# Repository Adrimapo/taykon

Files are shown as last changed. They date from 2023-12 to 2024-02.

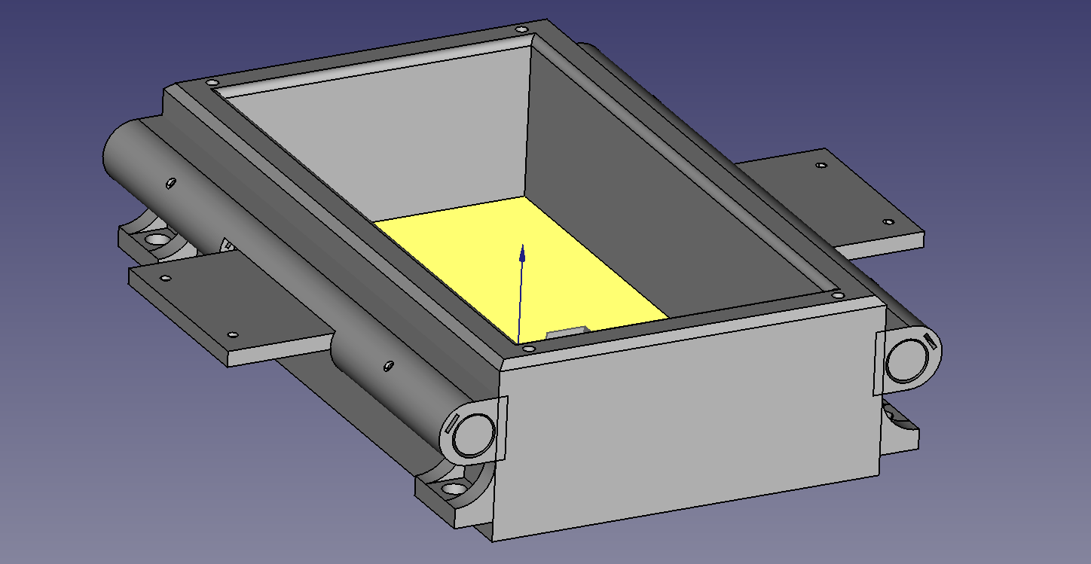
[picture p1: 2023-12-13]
resources/resources_shell/concepto-inicial.png

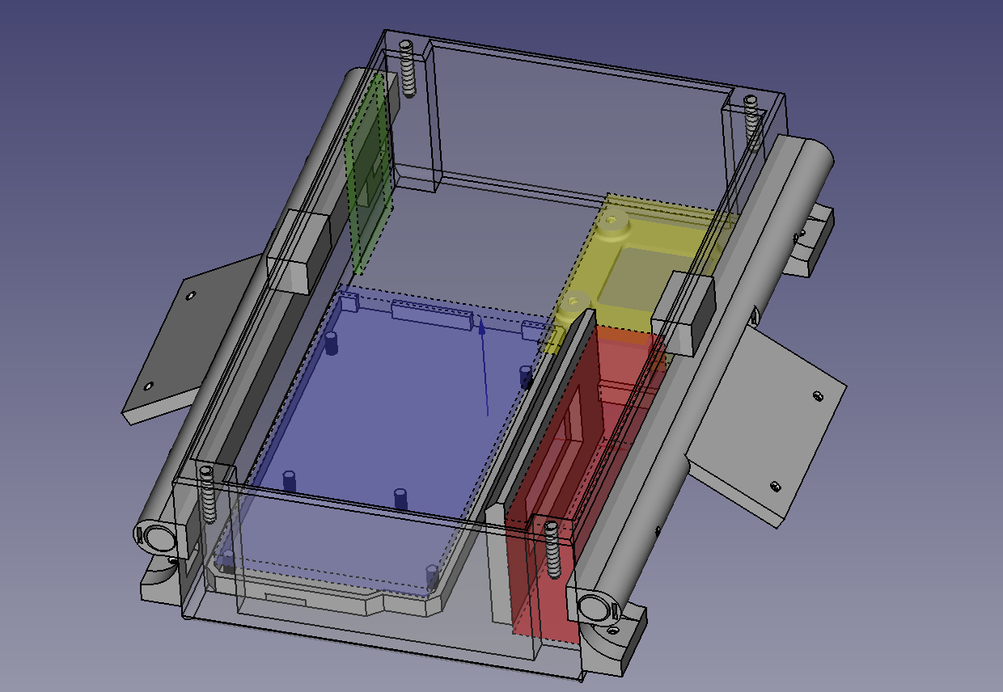
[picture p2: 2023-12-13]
resources/resources_shell/nueva-dis-int.png

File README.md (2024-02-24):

# Taykon

### Click on the image to be redirected to the project wiki

<p align="center">
  <a href="https://github.com/Adrimapo/Mecatronica-proyecto/wiki">
        TayKon_logo
    </a>
</p>

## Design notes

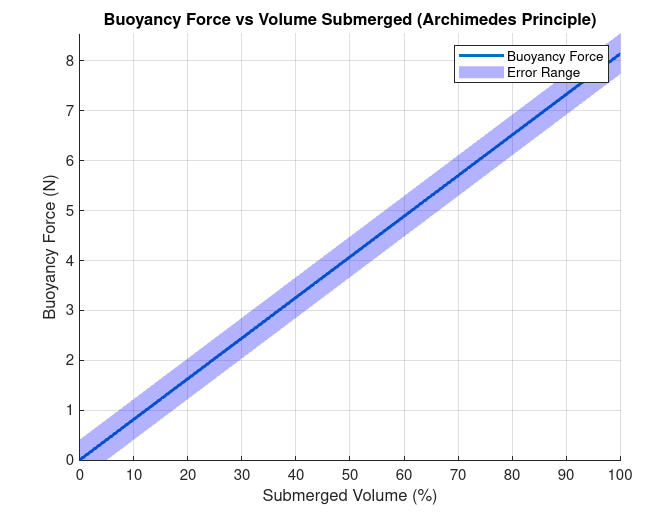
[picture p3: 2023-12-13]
resources/resources_buoyancy/buoyancy.png

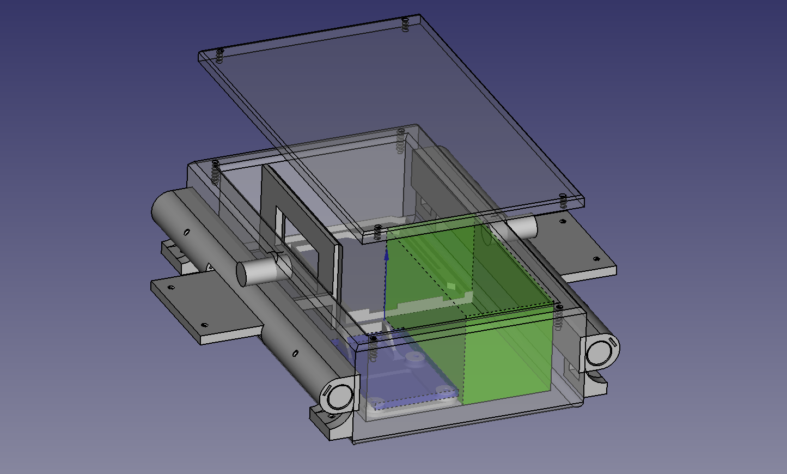
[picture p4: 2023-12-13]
resources/resources_shell/primera-version-brazos-grandes.png

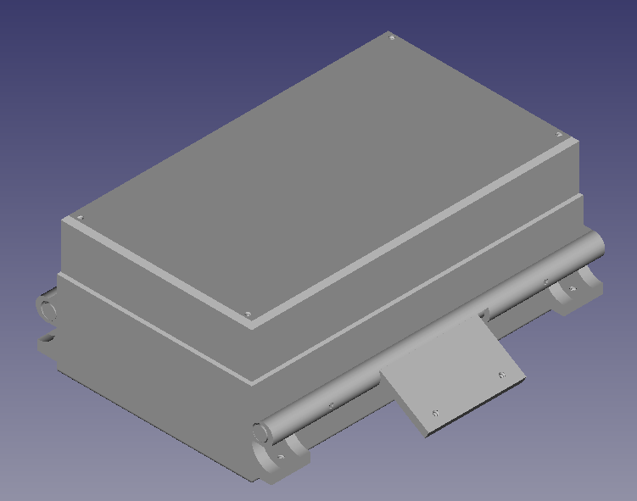
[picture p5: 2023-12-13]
resources/resources_shell/final_preview.png

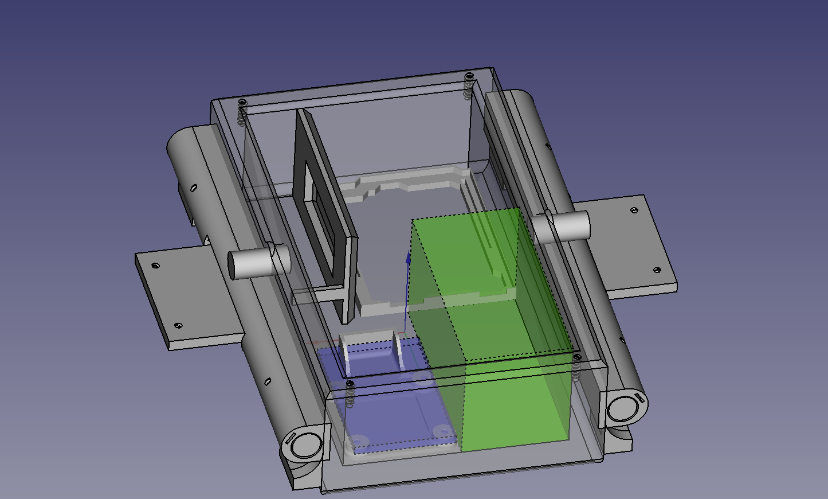
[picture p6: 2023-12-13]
resources/resources_shell/distribucion-interior.png

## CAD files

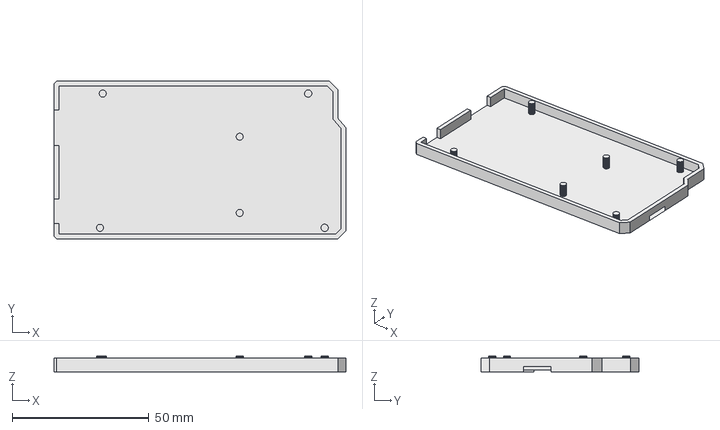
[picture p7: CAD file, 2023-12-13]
freeCad/arduino-case/arduino-mega-case.FCStd
106.6 x 57.6 x 5.80 mm

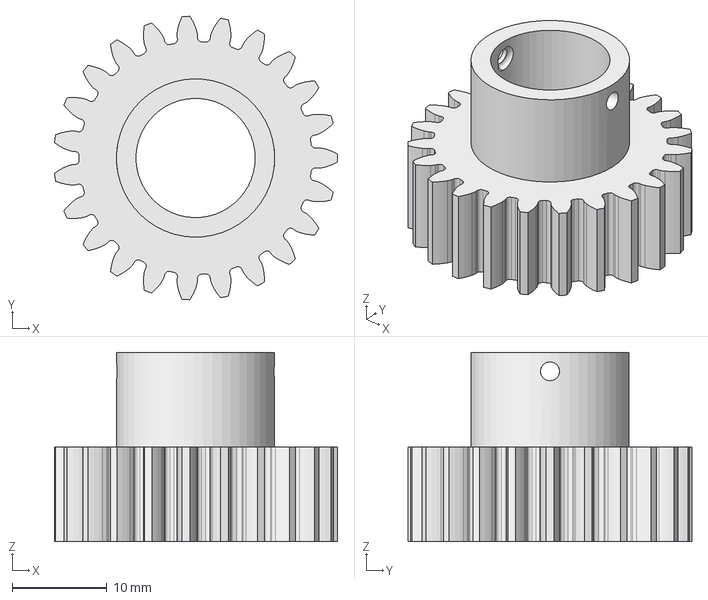
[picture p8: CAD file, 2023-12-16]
freeCad/brazos/engranajes.FCStd
29.9 x 30.0 x 20.0 mm

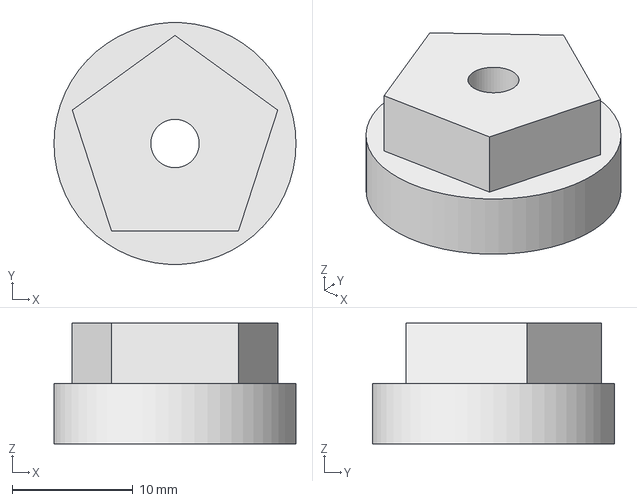
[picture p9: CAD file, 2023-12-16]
freeCad/eslavon_motor.FCStd
20.0 x 20.0 x 10.0 mm

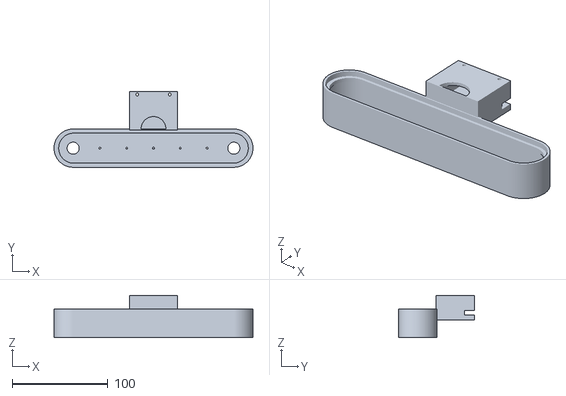
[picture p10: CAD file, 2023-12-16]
stl/Brazo/brazo.stl
208.0 x 79.0 x 44.0

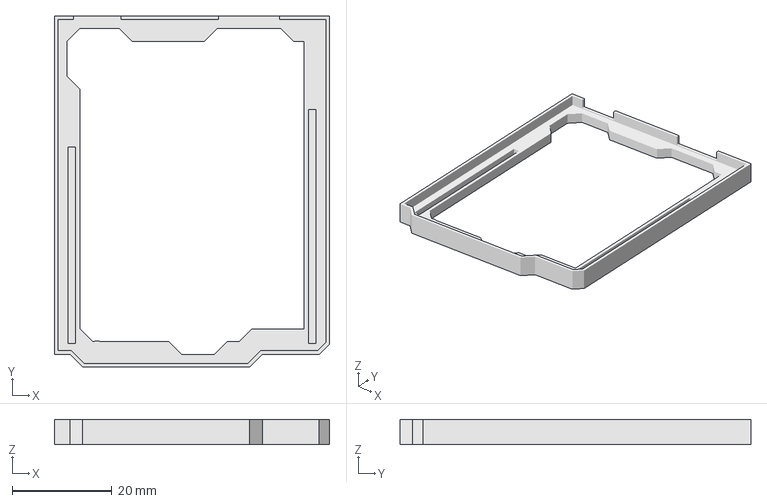
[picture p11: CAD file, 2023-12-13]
freeCad/arduino-case/arduino-uno-case.FCStd
55.2 x 70.5 x 5.08 mm

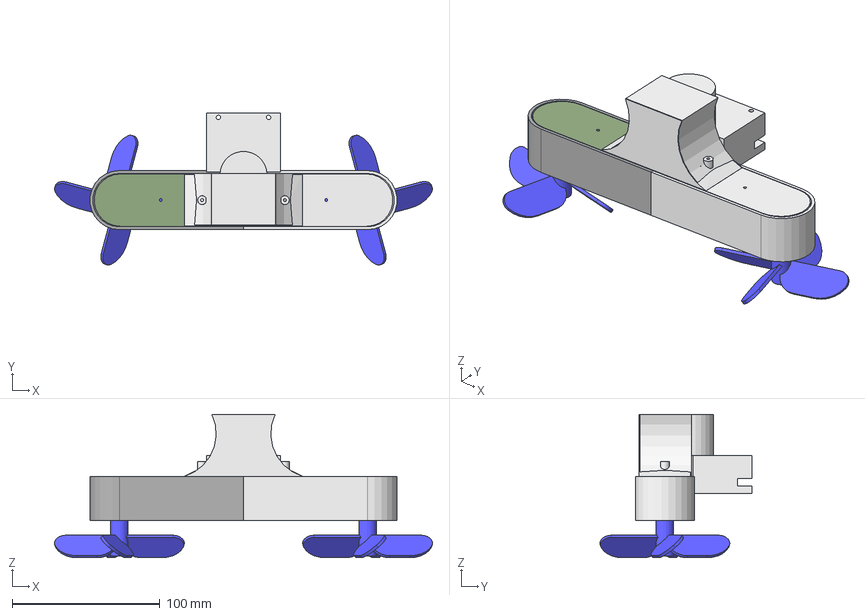
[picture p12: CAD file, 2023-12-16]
freeCad/brazos/brazo_completo.FCStd
255.9 x 102.9 x 97.1 mm
Engranajes002
Engranajes003
Engranaje_motor001
Engranaje_helice001
Eje005
Eje006
Helice_izquierda
Fusion001014 (Mirror #7)
Espejo_tapa
Eje006 (Mirror #9)
Eje005 (Mirror #8)
Engranaje_helice001 (Mirror #7)
Engranajes003 (Mirror #5)
Engranajes002 (Mirror #4)
Helice_izquierda (Mirror #10)
Sup_motor

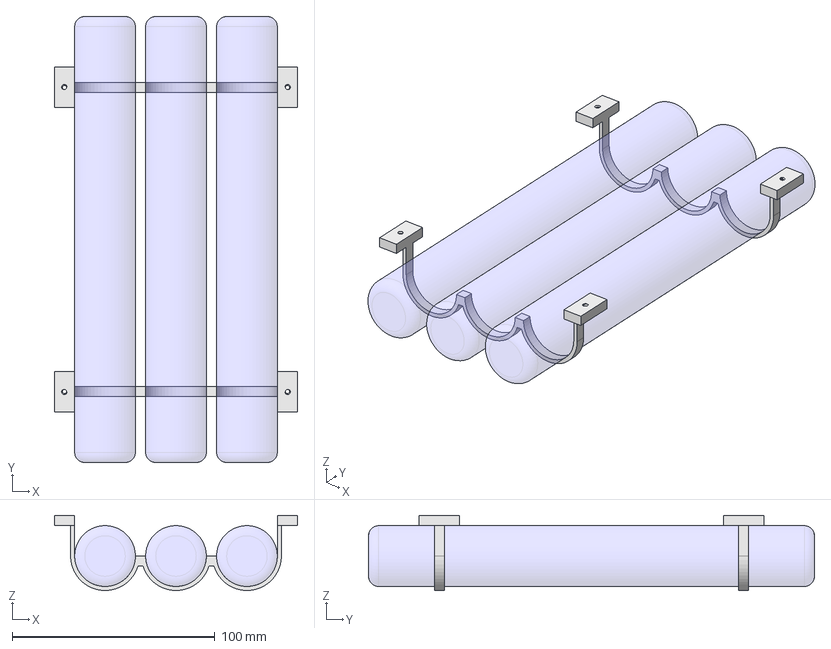
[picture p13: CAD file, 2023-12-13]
freeCad/tanques-flotabilidad.FCStd
120.0 x 220.0 x 37.0 mm
tanque
tanque001
tanque002
sujecion-flotadores
sujecion-flotadores (Mirror #13)

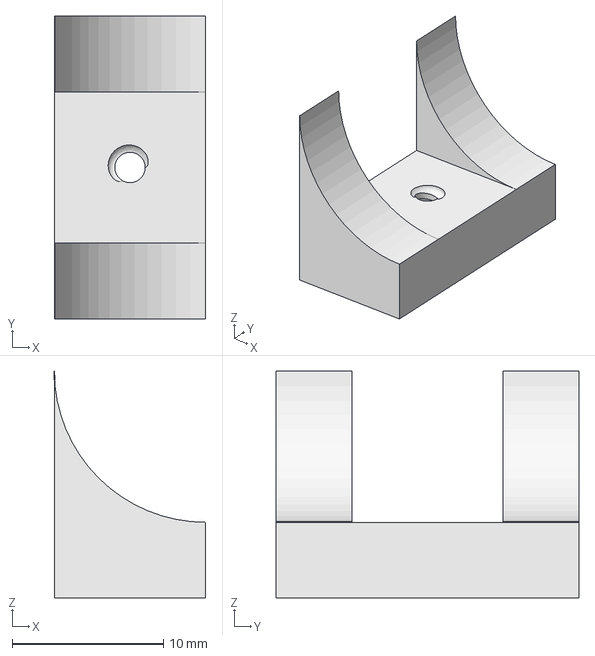
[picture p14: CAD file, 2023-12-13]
freeCad/acople-flotador.FCStd
10.0 x 20.0 x 15.0 mm

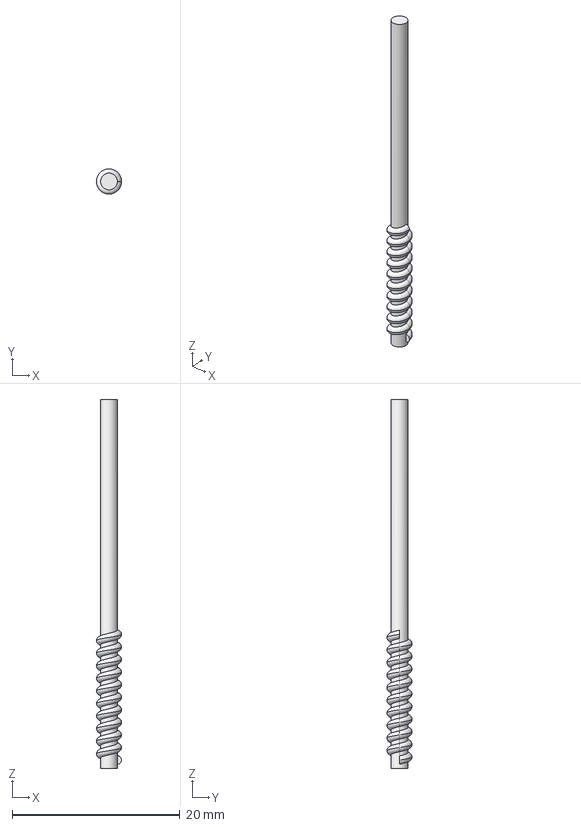
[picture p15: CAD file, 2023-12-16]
freeCad/brazos/roscas.FCStd
3.00 x 3.00 x 44.0 mm

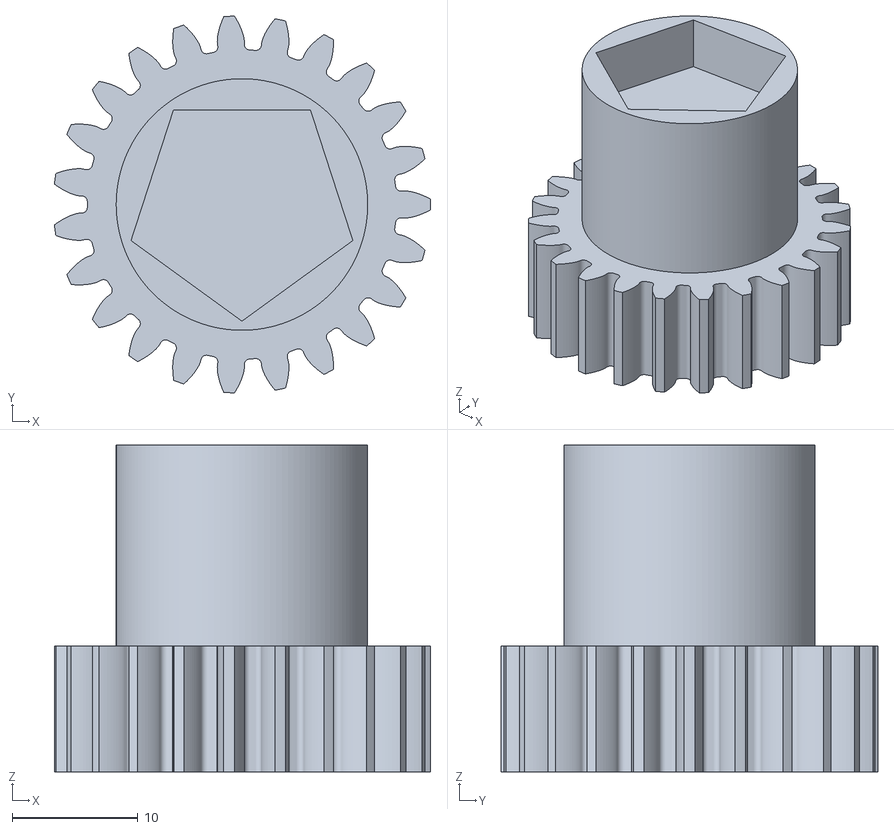
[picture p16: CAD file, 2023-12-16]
stl/Brazo/engranaje_motor.stl
29.9 x 30.0 x 26.0

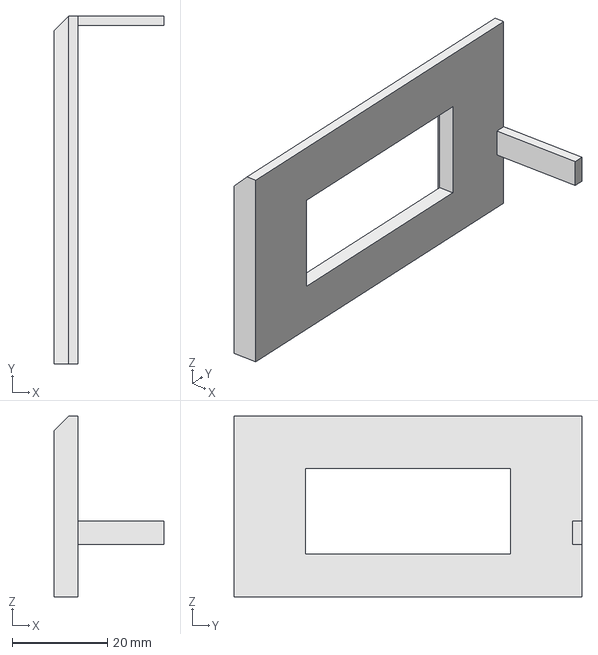
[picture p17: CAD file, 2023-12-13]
freeCad/rejillas-lipo.FCStd
23.0 x 73.0 x 38.0 mm

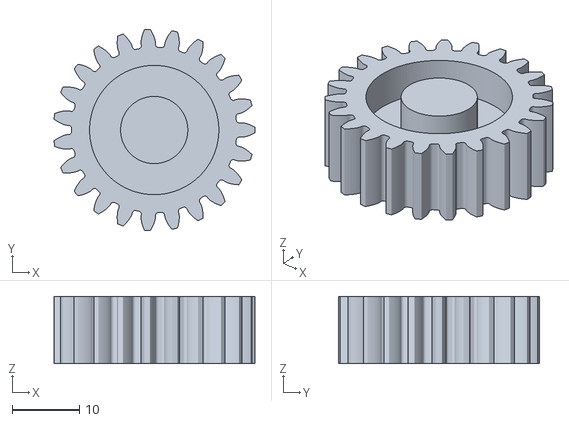
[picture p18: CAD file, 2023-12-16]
stl/Brazo/engranaje_intermedio.stl
29.9 x 30.0 x 10.0

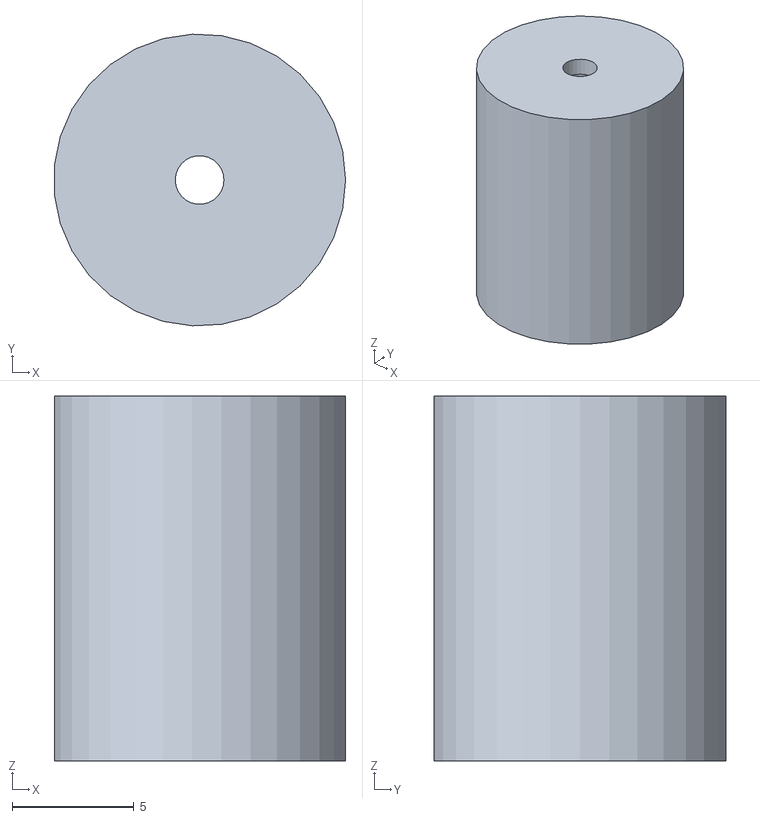
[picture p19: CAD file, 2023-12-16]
stl/Brazo/eje_engranaje_intermedio.stl
12.0 x 12.0 x 15.0

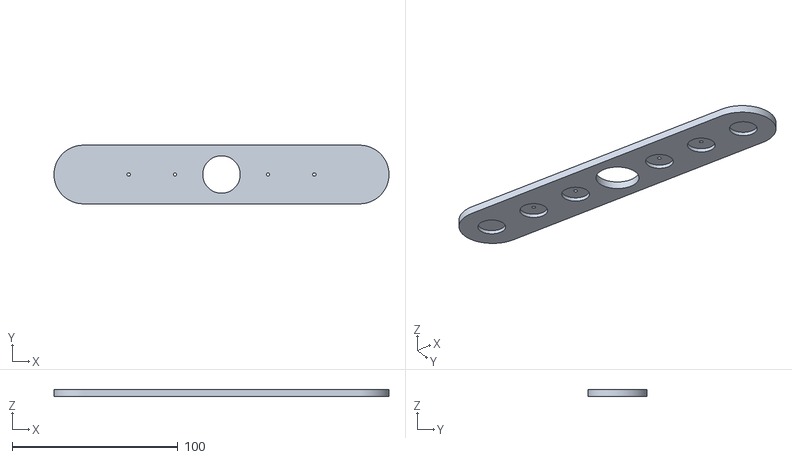
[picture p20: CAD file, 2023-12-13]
stl/Brazo/tapa_brazo.stl
202.2 x 35.4 x 4.00

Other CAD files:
stl/Brazo/eslavon_motor.stl
freeCad/brazos/eslavon_motor.FCStd
stl/Brazo/engranaje_helice.stl
stl/Brazo/tapa_motor.stl
stl/acople_flotador.stl

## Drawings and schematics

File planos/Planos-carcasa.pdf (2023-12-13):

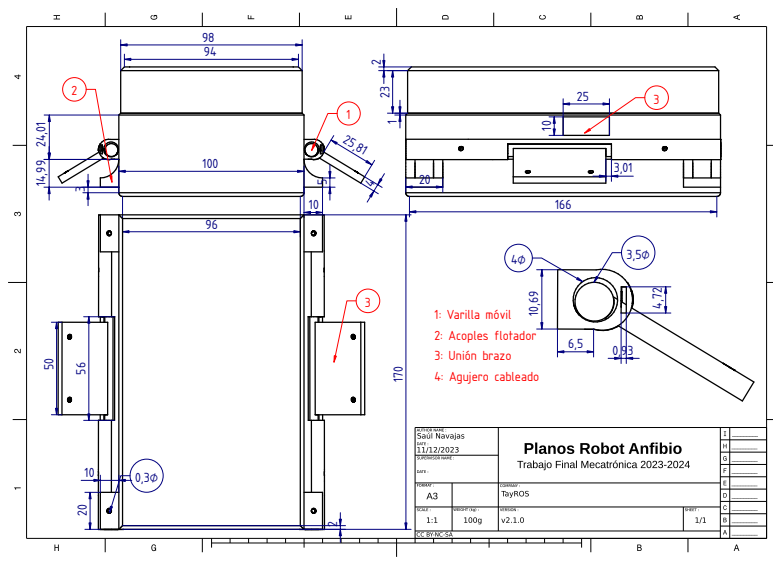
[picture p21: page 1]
1: Varilla móvil 2: Acoples flotador 3: Unión brazo 4: Agujero cableado

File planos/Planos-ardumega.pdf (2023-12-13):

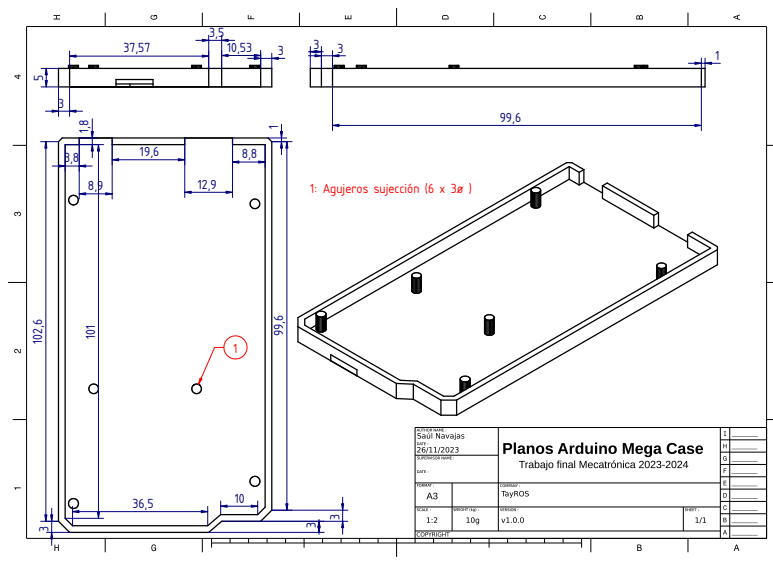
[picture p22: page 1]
1: Agujeros sujección (6 x 3ø )

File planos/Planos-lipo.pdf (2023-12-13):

5

47

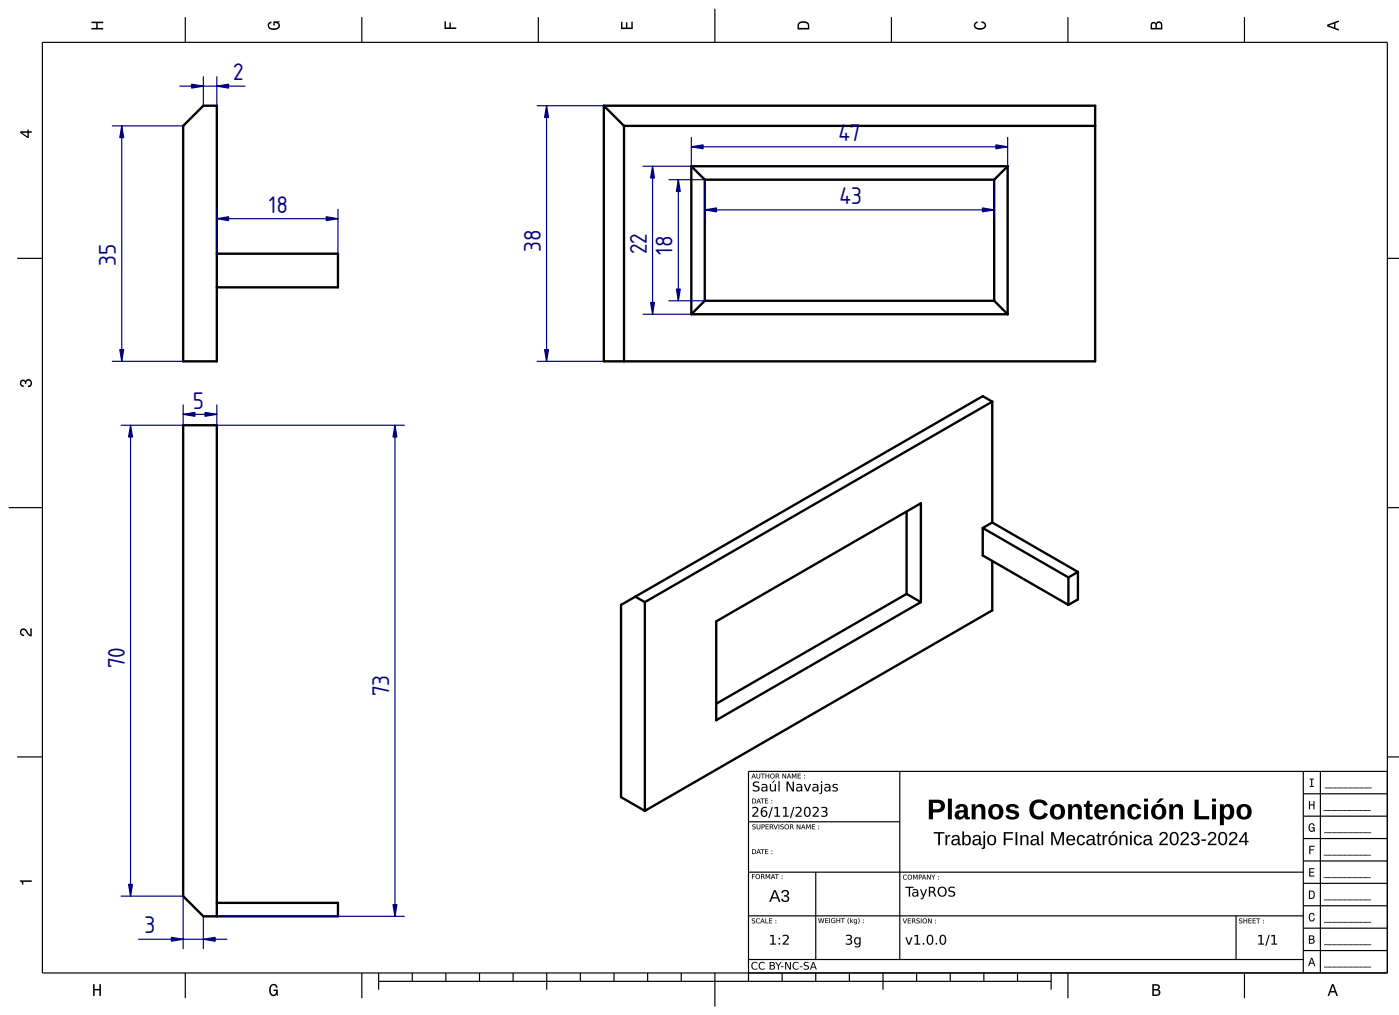
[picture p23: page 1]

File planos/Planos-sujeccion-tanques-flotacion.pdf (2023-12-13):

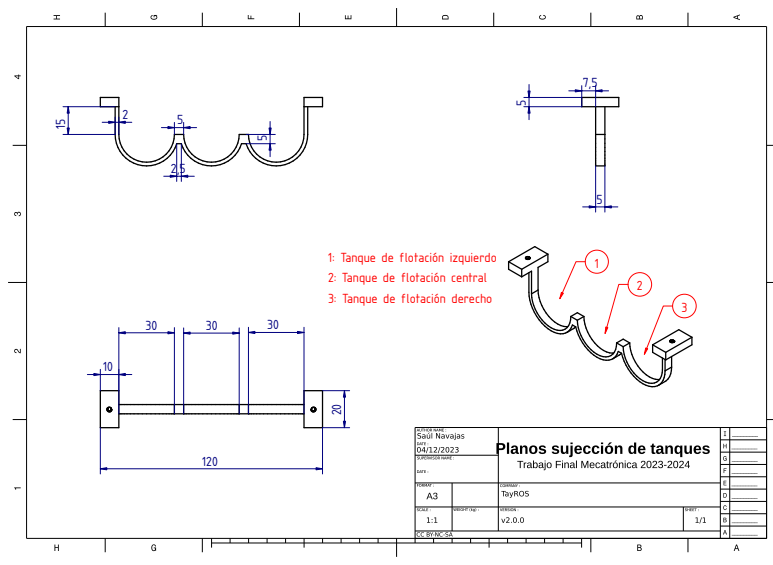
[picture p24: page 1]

1: Tanque de flotación izquierdo
2: Tanque de flotación central
3: Tanque de flotación derecho

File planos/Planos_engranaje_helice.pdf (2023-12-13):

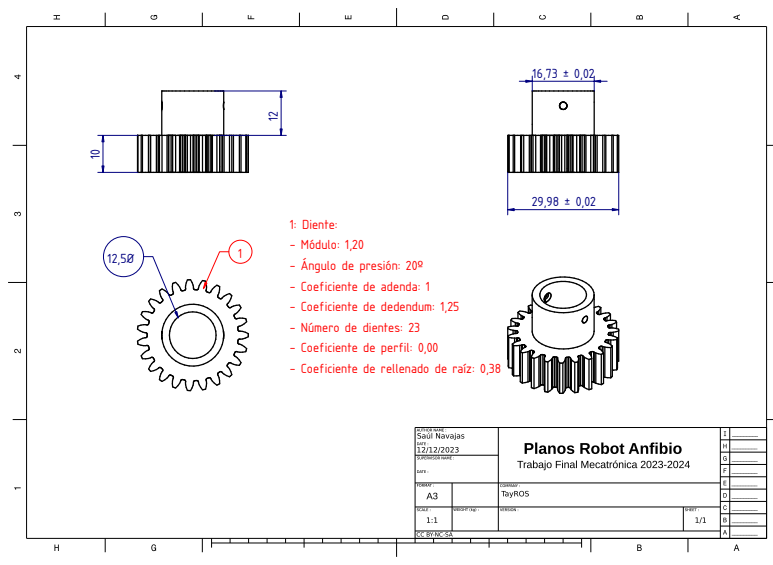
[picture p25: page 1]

1: Diente: - Módulo: 1,20
- Ángulo de presión: 20º
- Coeficiente de adenda: 1 - Coeficiente de dedendum: 1,25

- Número de dientes: 23
- Coeficiente de perfil: 0,00
- Coeficiente de rellenado de raíz: 0,38

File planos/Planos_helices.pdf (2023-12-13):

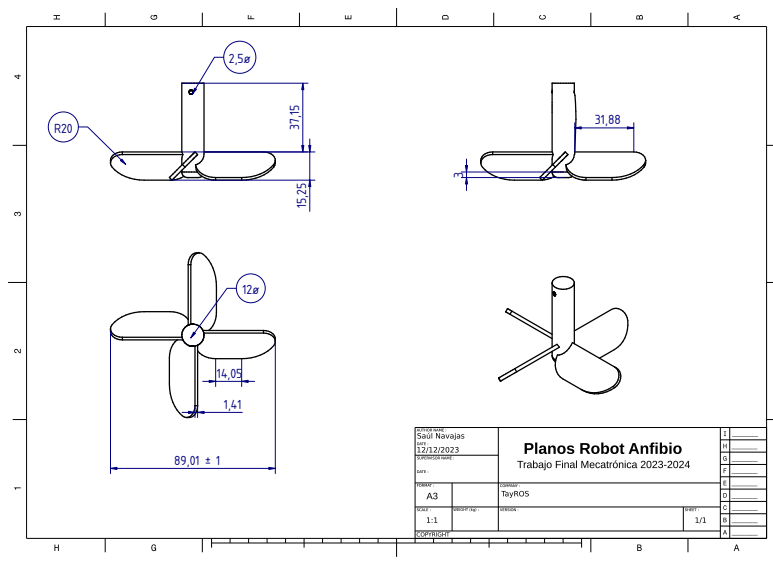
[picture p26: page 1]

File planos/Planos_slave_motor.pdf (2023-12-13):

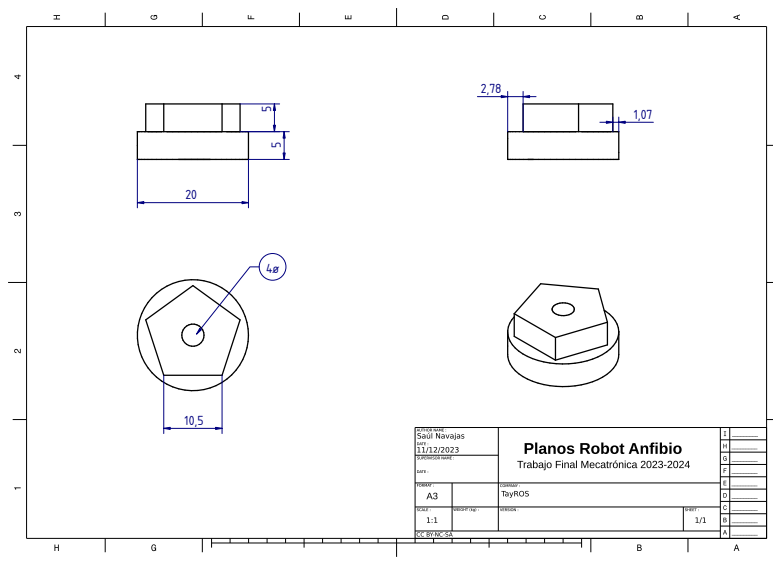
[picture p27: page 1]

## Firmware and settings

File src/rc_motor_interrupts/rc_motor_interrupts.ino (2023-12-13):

/*
  Arduino brushless motor control with rc controller
    by TayROS for URJC 
*/
 
#include <Servo.h>

// Define Input Connections
#define CH1 21
#define CH2 20
#define CH3 19
#define CH4 18
#define CH5 2
#define CH6 3
#define MOTOR_PIN 9

// Consts
const int CH1_MIN_RANGE = -100;
const int CH1_MAX_RANGE = 100;
const int CH1_DEF_VALUE = 0;

const int CH2_MIN_RANGE = -100;
const int CH2_MAX_RANGE = 100;
const int CH2_DEF_VALUE = 0;

const int CH3_MIN_RANGE = 0;
const int CH3_MAX_RANGE = 100;
const int CH3_DEF_VALUE = 0;

const int CH4_MIN_RANGE = -100;
const int CH4_MAX_RANGE = 100;
const int CH4_DEF_VALUE = 0;

const int CH5_MIN_RANGE = 0;
const int CH5_MAX_RANGE = 3;
const int CH5_DEF_VALUE = 0;

const bool CH6_DEF_VALUE = false;


// Channels values
int ch1Value;
int ch2Value;
int ch3Value;
int ch4Value; 
int ch5Value;
bool ch6Value;

// ESC values
Servo ESC;
int esc_val;

// Debouncing system
const int DEBOUNCE_DELAY = 50;
unsigned long last_debounce_time = 0;
 

int read_channel(int channelInput, int minLimit, int maxLimit, int defaultValue){
  int ch = pulseIn(channelInput, HIGH, 30000);
  if (ch < 100) return defaultValue;
  return map(ch, 1000, 2000, minLimit, maxLimit);
}
 
bool read_switch(byte channelInput, bool defaultValue){
  int intDefaultValue = (defaultValue)? 100: 0;
  int ch = read_channel(channelInput, 0, 100, intDefaultValue);
  return (ch > 50);
}

void print_channels_values(){
  Serial.print("Ch1: ");
  Serial.print(ch1Value);
  Serial.print(" | Ch2: ");
  Serial.print(ch2Value);
  Serial.print(" | Ch3: ");
  Serial.print(ch3Value);
  Serial.print(" | Ch4: ");
  Serial.print(ch4Value);
  Serial.print(" | Ch5: ");
  Serial.print(ch5Value);
  Serial.print(" | Ch6: ");
  Serial.println(ch6Value);
}

void read_all_channels(){
  ch1Value = read_channel(CH1, CH1_MIN_RANGE, CH1_MAX_RANGE, CH1_DEF_VALUE);
  ch2Value = read_channel(CH2, CH2_MIN_RANGE, CH2_MAX_RANGE, CH2_DEF_VALUE);
  ch3Value = read_channel(CH3, CH3_MIN_RANGE, CH3_MAX_RANGE, CH3_DEF_VALUE);
  ch4Value = read_channel(CH4, CH4_MIN_RANGE, CH4_MAX_RANGE, CH4_DEF_VALUE);
  ch5Value = read_channel(CH5, CH5_MIN_RANGE, CH5_MAX_RANGE, CH5_DEF_VALUE);
  ch6Value = read_switch(CH6, CH6_DEF_VALUE);
}

// Interruptions treatment
void channel_interruption(){

  // Debouncing
  unsigned long current_time = millis();
  if (current_time - last_debounce_time < DEBOUNCE_DELAY) {
    return;
  }
  last_debounce_time = current_time;

  read_all_channels();
  print_channels_values();
}


void setup(){
  // Set up serial monitor
  Serial.begin(115200);
  
  // Set all pins as inputs
  pinMode(CH1, INPUT);
  pinMode(CH2, INPUT);
  pinMode(CH3, INPUT);
  pinMode(CH4, INPUT);
  pinMode(CH5, INPUT);
  pinMode(CH6, INPUT);

  // Set all interruptions
  attachInterrupt(digitalPinToInterrupt(CH1), channel_interruption, CHANGE);
  attachInterrupt(digitalPinToInterrupt(CH2), channel_interruption, CHANGE);
  attachInterrupt(digitalPinToInterrupt(CH3), channel_interruption, CHANGE);
  attachInterrupt(digitalPinToInterrupt(CH4), channel_interruption, CHANGE);
  attachInterrupt(digitalPinToInterrupt(CH5), channel_interruption, CHANGE);
  attachInterrupt(digitalPinToInterrupt(CH6), channel_interruption, CHANGE);

  // ESC control
  ESC.attach(9,1000,2000);
}
 

void loop() {

  // CH3 control te motor
  esc_val = map(ch3Value, CH3_MIN_RANGE, CH3_MAX_RANGE, 0, 180); 

  Serial.print("Motor speed: ");
  Serial.println(esc_val);

  ESC.write(esc_val);
  delay(100);

}

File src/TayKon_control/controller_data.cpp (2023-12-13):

#include "Arduino.h"
#include "controller_data.h"

ControllerData::ControllerData(int channel2Pin, int channel3Pin, int channel4Pin, int channel5Pin, int channel6Pin) {

  // Set up serial monitor
  Serial.begin(115200);

  // Set all pins as inputs
  CH2_pin = channel2Pin;
  CH3_pin = channel3Pin;
  CH4_pin = channel4Pin;
  CH5_pin = channel5Pin;
  CH6_pin = channel6Pin;

  pinMode(CH2_pin, INPUT);
  pinMode(CH3_pin, INPUT);
  pinMode(CH4_pin, INPUT);
  pinMode(CH5_pin, INPUT);
  pinMode(CH6_pin, INPUT);

  // Data init
  status_on_off = OFF;
  control_mode = 0;
  Rmotor_power = 0;
  Lmotor_power = 0;
  twist = 0;

  update_values();
}

int ControllerData::read_channel(int channelInput, int minLimit, int maxLimit, int defaultValue) {
  int ch = pulseIn(channelInput, HIGH, PULSE_TIMEOUT);
  if (ch < MIN_CHANNEL_VALUE) return defaultValue;
  return map(ch, CHANNEL_MIN_IN_VAL, CHANNEL_MAX_IN_VAL, minLimit, maxLimit);
}

bool ControllerData::read_switch(int channelInput, bool defaultValue){
  int intDefaultValue = (defaultValue)? 100: 0;
  int ch = read_channel(channelInput, 0, 100, intDefaultValue);
  return (ch > 50);
}


void ControllerData::update_values(){

  // Raw Data
  channel2Value = read_channel(CH2_pin, CH2_MIN_RANGE, CH2_MAX_RANGE, CH2_DEF_VALUE);
  channel3Value = read_channel(CH3_pin, CH3_MIN_RANGE, CH3_MAX_RANGE, CH3_DEF_VALUE);
  channel4Value = read_channel(CH4_pin, CH4_MIN_RANGE, CH4_MAX_RANGE, CH4_DEF_VALUE);
  channel5Value = read_channel(CH5_pin, CH5_MIN_RANGE, CH5_MAX_RANGE, CH5_DEF_VALUE);
  channel6Value = read_switch(CH6_pin, CH6_DEF_VALUE);

  // Proccesed data
  status_on_off = channel6Value;
  control_mode = channel5Value;

  procces_movement_data();
}

int clampInt(int valor, int minimo, int maximo) {
    return max(minimo, min(valor, maximo));
}

void ControllerData::procces_movement_data(){

  if(status_on_off == OFF){
    Rmotor_power = 0;
    Lmotor_power = 0;
    twist = 0;
  }
  else{
    switch(control_mode) {
      case 0:
          Rmotor_power = map(channel3Value, 0, 100, MIN_MOTOR_POWER, MAX_MOTOR_POWER);
          Lmotor_power = map(channel3Value, 0, 100, MIN_MOTOR_POWER, MAX_MOTOR_POWER);
          twist = 0;
          break;

      case 1:
          int recived_power = channel3Value;
          int recived_twist = channel2Value;
          float twist_percent = 1 - (abs(recived_twist) / 100.0);
          int L_vel = 0;
          int R_vel = 0;

          if(recived_twist < 0){
            L_vel = recived_power * twist_percent;
            R_vel = recived_power * (1 + (1 - twist_percent));
          }
          else{
            R_vel = recived_power * twist_percent;
            L_vel = recived_power * (1 + (1 - twist_percent));
          }

          // Limit between 0 and 100 and map value to motor speed
          L_vel = clampInt(L_vel, CH3_MIN_RANGE, CH3_MAX_RANGE);
          R_vel = clampInt(R_vel, CH3_MIN_RANGE, CH3_MAX_RANGE);

          Lmotor_power = map(L_vel, CH3_MIN_RANGE, CH3_MAX_RANGE, MIN_MOTOR_POWER, MAX_MOTOR_POWER);
          Rmotor_power = map(R_vel, CH3_MIN_RANGE, CH3_MAX_RANGE, MIN_MOTOR_POWER, MAX_MOTOR_POWER);
          twist = channel2Value;
          break;

      case 2:
          Rmotor_power = map(channel3Value, 0, 100, MIN_MOTOR_POWER, MAX_MOTOR_POWER);
          Lmotor_power = map(channel2Value, 0, 100, MIN_MOTOR_POWER, MAX_MOTOR_POWER);
          twist = 0;
          break;
    }
  }
}

void ControllerData::print_raw_values_table() {
  Serial.println("=======================================");
  Serial.println("\nActual Raw Values:");
  Serial.print("| CH2: ");
  Serial.print(channel2Value);
  Serial.print(" | CH3: ");
  Serial.print(channel3Value);
  Serial.print(" | CH4: ");
  Serial.print(channel4Value);
  Serial.print(" | CH5: ");
  Serial.print(channel5Value);
  Serial.print(" | CH6: ");
  Serial.println(channel6Value);
  Serial.println("=======================================");
}

void ControllerData::print_processed_values_table() {
  Serial.println("=======================================");
  Serial.println("\nActual Processed Values:");
  if(status_on_off == OFF){
    Serial.print("| Status: OFF");
  }
  else{
    Serial.print("| Status: ON");
  }

  switch(control_mode) {
      case 0:
          Serial.print(" | Control Mode: Simple");
          break;
      case 1:
          Serial.print(" | Control Mode: Twist Control");
          break;
      case 2:
          Serial.print(" | Control Mode: Testing mode");
          break;
  }
  Serial.print(" | R Motor Power: ");
  Serial.print(Rmotor_power);
  Serial.print(" | L Motor Power: ");
  Serial.print(Lmotor_power);
  Serial.print(" | Twist: ");
  Serial.println(twist);
  Serial.println("=======================================");
}

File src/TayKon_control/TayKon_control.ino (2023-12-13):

/*
  Arduino brushless motor control with rc controller
    by TayROS for URJC 
*/
 
#include <Servo.h>
#include <Thread.h>
#include <StaticThreadController.h>
#include <ThreadController.h>
#include "controller_data.h"

// Define Input Connections
#define CH2 20
#define CH3 19
#define CH4 18
#define CH5 2
#define CH6 3
#define R_MOTOR_PIN 9
#define L_MOTOR_PIN 10

const bool DEBUG = false;

// ESC values
Servo R_ESC;
Servo L_ESC;
int esc_val;

// Controller
ControllerData TayKon_controller(CH2, CH3, CH4, CH5, CH6);


void setup(){
  // Set up serial monitor
  Serial.begin(115200);
  
  // ESC control
  R_ESC.attach(R_MOTOR_PIN,1000,2000);
  L_ESC.attach(L_MOTOR_PIN,1000,2000);
}
 

void loop() {

  //-- Update the controller values
  TayKon_controller.update_values();

  //-- Debug info
  if(DEBUG){
    TayKon_controller.print_raw_values_table();
    TayKon_controller.print_processed_values_table();
  }

  //-- Write controller data into ESCs
  R_ESC.write(TayKon_controller.get_Rmotor_power());
  L_ESC.write(TayKon_controller.get_Lmotor_power());

  if(DEBUG){
    delay(500);
  }
}

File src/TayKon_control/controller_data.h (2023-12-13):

#ifndef CONTROLLER_DATA_H
#define CONTROLLER_DATA_H

class ControllerData {
public:
  // Constructor
  ControllerData(int channel2Pin, int channel3Pin, int channel4Pin, int channel5Pin, int channel6Pin);

  void update_values();
  void print_raw_values_table();
  void print_processed_values_table();

  // Getters
  bool get_status_on_off(){ return status_on_off; }
  int get_control_mode(){ return control_mode; }
  int get_Rmotor_power(){ return Rmotor_power; }
  int get_Lmotor_power(){ return Lmotor_power; }
  int get_twist(){ return twist; }

  enum Status : bool{
    OFF = false,
    ON = true
  };

private:

  // Pins
  int CH2_pin;
  int CH3_pin;
  int CH4_pin;
  int CH5_pin;
  int CH6_pin;


  // Raw data
  int channel2Value;
  int channel3Value;
  int channel4Value;
  int channel5Value;
  bool channel6Value;

  // Processed data
  bool status_on_off; // off = false, on = true
  int control_mode;   // 0 = simple control(only straight), 1 = twist control 2 = not defined
  int Rmotor_power;
  int Lmotor_power;
  int twist;          // -100/100(left/right)

  // Private functions
  int read_channel(int channelInput, int minLimit, int maxLimit, int defaultValue);
  bool read_switch(int channelInput, bool defaultValue);
  void procces_movement_data();

  // Consts
  const int CH2_MIN_RANGE = -100;
  const int CH2_MAX_RANGE = 100;
  const int CH2_DEF_VALUE = 0;

  const int CH3_MIN_RANGE = 0;
  const int CH3_MAX_RANGE = 100;
  const int CH3_DEF_VALUE = 0;

  const int CH4_MIN_RANGE = -100;
  const int CH4_MAX_RANGE = 100;
  const int CH4_DEF_VALUE = 0;

  const int CH5_MIN_RANGE = 0;
  const int CH5_MAX_RANGE = 3;
  const int CH5_DEF_VALUE = 0;

  const bool CH6_DEF_VALUE = false;

  const int CHANNEL_MIN_IN_VAL = 1000;
  const int CHANNEL_MAX_IN_VAL = 2000;
  const int PULSE_TIMEOUT = 30000;
  const int MIN_CHANNEL_VALUE = 100;

  const int MIN_MOTOR_POWER = 0;
  const int MAX_MOTOR_POWER = 180;

};

#endif

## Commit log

2023-11-14 First models
    [engranajes.FCStd, soporte_motor.FCStd]
2023-11-16 Rosca y brazo
    [helice.FCStd, roscas.FCStd, soporte_motor.FCStd]
2023-11-18 Thingverse things
    [Ex01_15x100x4.stl, Ex02_nut_24x8_15x4.stl, Ex03_15x30x4.stl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]
2023-11-19 Ready for first trials
    [Ex01_15x100x4.stl, Ex02_nut_24x8_15x4.stl, Ex03_15x30x4.stl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]
2023-11-19 Shell, arm and floating hitch models
    [Ex01_15x100x4.stl, Ex02_nut_24x8_15x4.stl, Ex03_15x30x4.stl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]
2023-11-20 Lipo Battery restriction in shell added
    [rejillas-lipo.FCStd]
2023-11-22 Arduino case model added
    [arduino-case.FCStd]
2023-11-23 Motor aprox
    [engranajes.FCStd, helice.FCStd]
2023-11-23 Helices y medidas motor
    [eslavon_motor.FCStd, helice.FCStd, soporte_motor.FCStd]
2023-11-25 Carcasa agujeros cuadrados modelo reducido + arduino mega option
    [arduino-mega-case.FCStd]
2023-11-26 First tests with Rc controller and motors(using interruptions)
2023-11-26 resources added and models joined in a dir
    [acople-flotador.FCStd, arduino-case.FCStd, arduino-mega-case.FCStd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]
2023-11-26 directories organized
    [acople-flotador.FCStd, arduino-case.FCStd, arduino-mega-case.FCStd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]
2023-11-30 Shell modified tubes for ESC
    [arduino-mega-case.FCStd, arduino-uno-case.FCStd]
2023-12-04 Added floating tank model, bluemap and resources
    [tanques-flotabilidad.FCStd]
2023-12-07 More changes
    [PrisioneroMotor.stl, eje.stl, engranaje_eje.stl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]
2023-12-11 All freecad models organized and main case bluemap fixed
2023-12-11 Floating tanks added to final model of case (v2.1.0)
2023-12-11 Physics graphs and resources of bouyancy and related added
    [acople-flotador.FCStd, arduino-mega-case.FCStd, arduino-uno-case.FCStd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]
2023-12-12 Models with bluemaps
    [eslavon_motor.FCStd]
2023-12-12 Added blueplanes of robot arm components
2023-12-16 FreeCads brazos
    [engranajes.FCStd, eslavon_motor.FCStd, roscas.FCStd]
